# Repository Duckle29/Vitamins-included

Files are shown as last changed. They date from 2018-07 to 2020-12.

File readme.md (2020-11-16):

View this project on [CADLAB.io](https://cadlab.io/project/1862).   
View the [iBOM](https://duckle29.github.io/Vitamins-included/ibom.html)

# Vitamins Included

This repository contains all files necesarry to make the Let's split keyboard variant "Vitamins included"

Files are not guarranteed to be in sync outside of tagged releases. They aren't on releases either, but they should be ;)

The kit for these PCBs are sold at [Novelkeys](https://novelkeys.xyz), 
the firmware for the keyboard is [QMK](https://github.com/qmk/qmk_firmware/tree/master/keyboards/vitamins_included)

To edit these, you need kicad 5 or later. Missing footprints can be found [here](https://github.com/Duckle29/kicad-footprints), on seperate branches, but should be included in KiCAD libraries eventually. You can check for open pull-requests by me on the upstream repo to see the status on those.

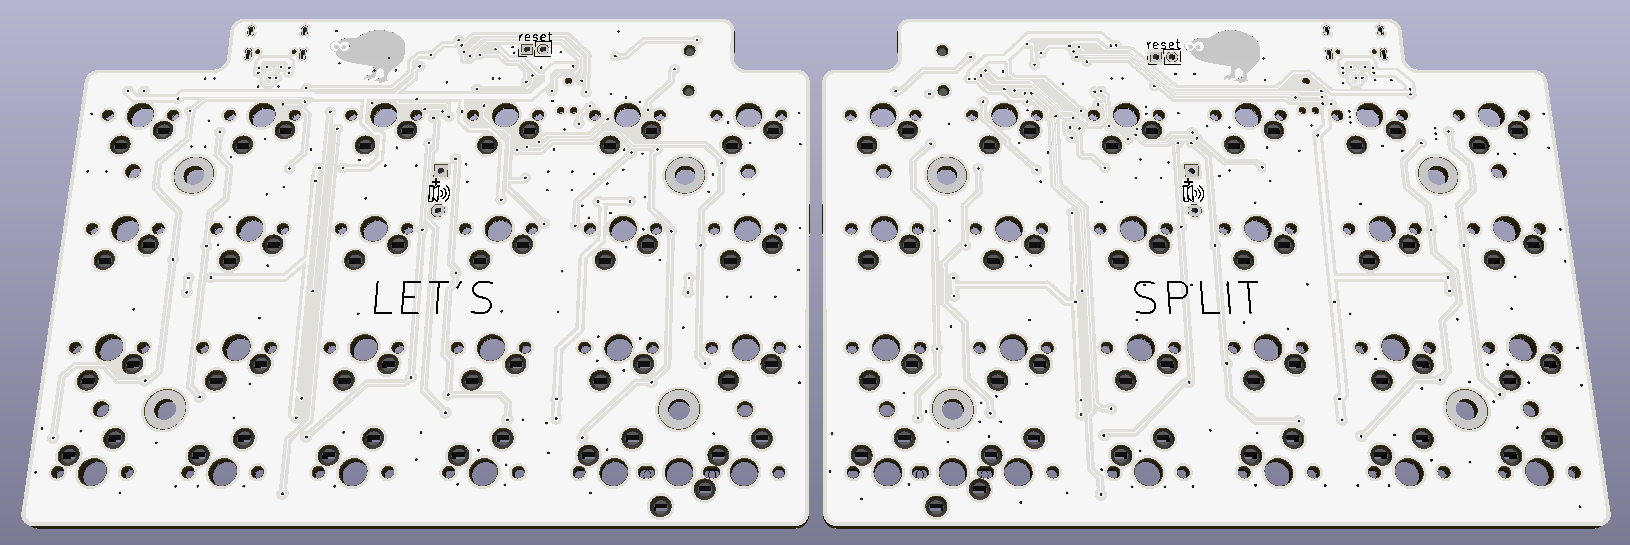
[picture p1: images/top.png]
top render

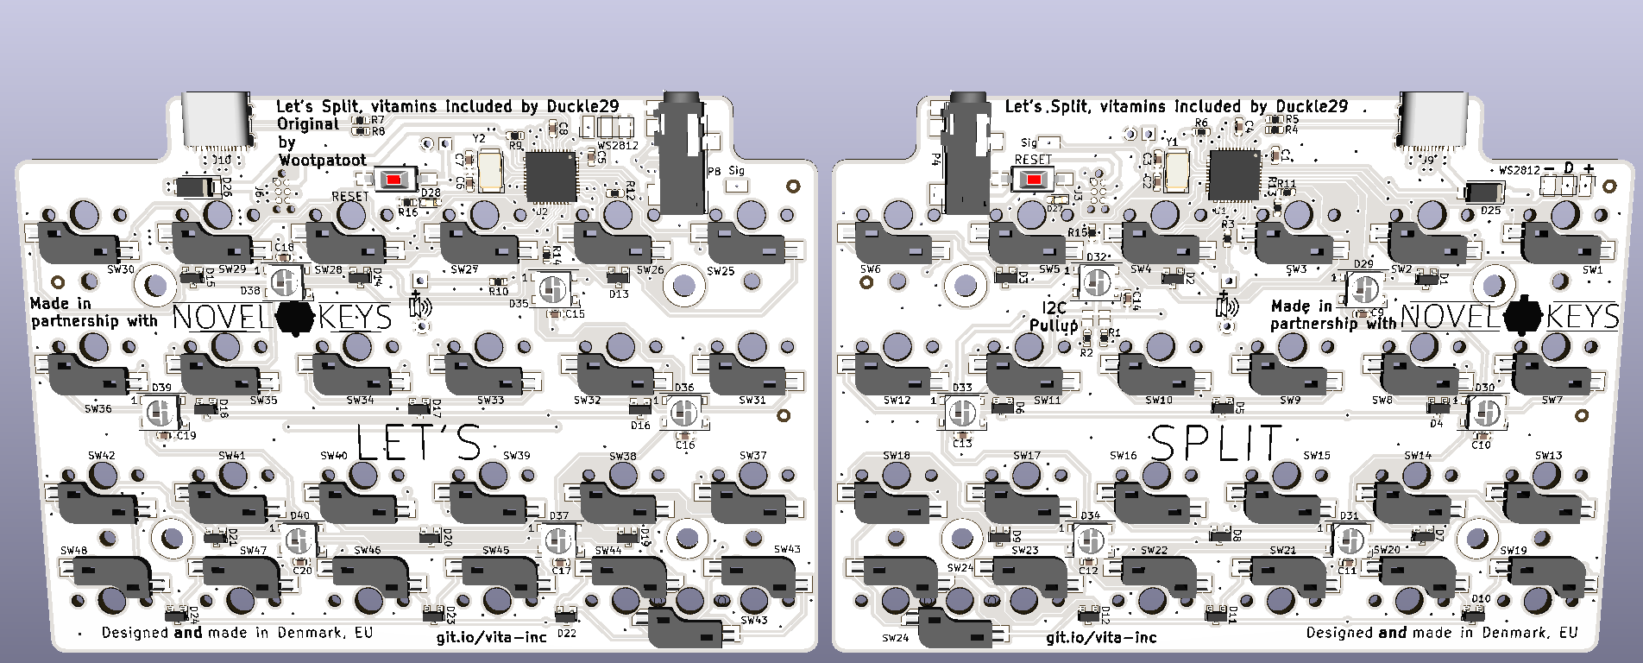
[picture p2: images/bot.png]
bottom render


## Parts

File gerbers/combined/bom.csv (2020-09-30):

Id | Designator | Package | Quantity | Designation | Supplier and ref
1 | R26,R25 | R_0603_1608Metric | 2 | 100k
2 | R24,R23,R22,R21,R13,R15,R3,R11,R16,R10,R12,R14 | R_0603_1608Metric | 12 | 220R
3 | SW6,SW29,SW14,SW22,SW17,SW9,SW1,SW20,SW15,SW23,SW7,SW8,SW11,SW12,SW21,SW4,SW24,SW18,SW5,SW2,SW19,SW16,SW3,SW13,SW10,SW24,SW43,SW30,SW48,SW35,SW32,SW39,SW28,SW40,SW27,SW38,SW46,SW33,SW26,SW34,SW36,SW43,SW44,SW42,SW37,SW41,SW47,SW31,SW25,SW45 | Kailh-socket | 50 | Socket
4 | D41,D44,D42,D43 | SOT-143 | 4 | PRTR5V0U2X
5 | D26,D25 | D_SMA | 2 | SS210ATR
6 | D6,D4,D8,D9,D10,D2,D1,D3,D7,D12,D11,D5,D22,D18,D23,D24,D21,D19,D15,D14,D13,D20,D17,D16 | SOT-23 | 24 | BAV70
7 | D30,D34,D33,D29,D31,D32,D35,D40,D36,D39,D37,D38 | LED_WS2812B_PLCC4_5.0x5.0mm_P3.2mm | 12 | WS2812B
8 | C3,C2,C7,C6 | C_0603_1608Metric | 4 | 18pF
9 | J3,J6 | Tag-Connect_TC2030-IDC-NL_2x03_P1.27mm_Vertical | 2 | ISP
10 | C9,C14,C13,C11,C4,C10,C1,C12,C19,C18,C16,C17,C15,C20,C5,C8 | C_0603_1608Metric | 16 | 1uF
11 | P3,P6 | SMD_PAD_1x03_Pitch2.54mm | 2 | WS2812
12 | JP5,JP6 | SolderJumper-3_P1.3mm_Bridged12_RoundedPad1.0x1.5mm | 2 | WS_OUT
13 | R1,R2,R6,R9 | R_0603_1608Metric | 4 | 4K7
14 | G***,G*** | kiwi12.5mm | 2 | LOGO
15 | J14,J7,J15,J12,J11,J13,J16,J17,J21,J24,J18,J8,J22,J19,J20,J23 | TestPoint_Pad_D1.5mm | 16 | Conn_01x01
16 | D27,D28 | LED_0603_1608Metric_Castellated | 2 | SML-D12U1WT86
17 | U1,U2 | QFN44G-0.5-7X7MM | 2 | ATMega32U4
18 | REF**,REF**,REF**,REF**,REF**,REF**,REF**,REF** | MountingHole_2.2mm_M2 | 8 | MountingHole_2.2mm_M2
19 | G***,G*** | NovelKeys | 2 | LOGO
20 | SW49,SW50 | SW_SPST_FSMSM | 2 | FSMSM
21 | REF**,REF**,REF**,REF**,REF**,REF**,REF**,REF** | 1pin | 8 | 1pin
22 | FID1,FID2,FID6,FID5,FID4,FID3 | Fiducial_1mm_Dia_2mm_Outer | 6 | Fiducial
23 | JP2,JP1 | Solder-jumper-NO | 2 | I2C pullup
24 | J2,J4 | PinHeader_1x02_P2.54mm_Vertical | 2 | reset
25 | Y1,Y2 | Crystal_SMD_Abracon_ABM3-2pin_5.0x3.2mm | 2 | 16MHz
26 | J9,J10 | USB_C_Receptacle_Palconn_UTC16-G | 2 | UTC16-G
27 | P4,P8 | SJ-4351X-SMT | 2 | SJ-43514-SMT
28 | R17,R18,R20,R19 | R_0603_1608Metric | 4 | 5K1
29 | J25,J26 | Buzzer_Mallory_AST1109MLTRQ | 2 | Buzzer_piezo
30 | J1 | Buzzer_12x9.5RM7.6 | 1 | Speaker
31 | JP4,JP3 | SolderJumper-3_P1.3mm_Bridged12_RoundedPad1.0x1.5mm | 2 | WS_MODE
32 | R4,R5,R7,R8 | R_0603_1608Metric | 4 | 22R
33 | J5 | Buzzer_12x9.5RM7.6 | 1 | Buzzer

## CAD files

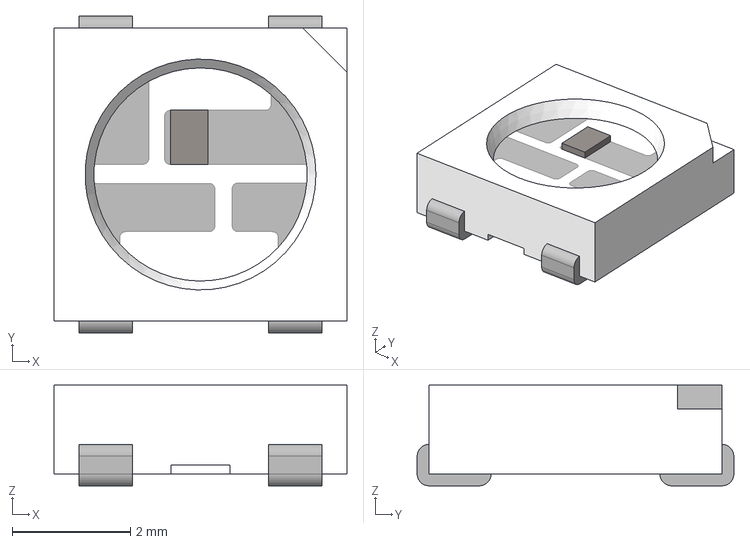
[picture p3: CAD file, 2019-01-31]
3D-models/WS2812_RGB_LED_updated.stp
4.95 x 5.35 x 1.70 mm

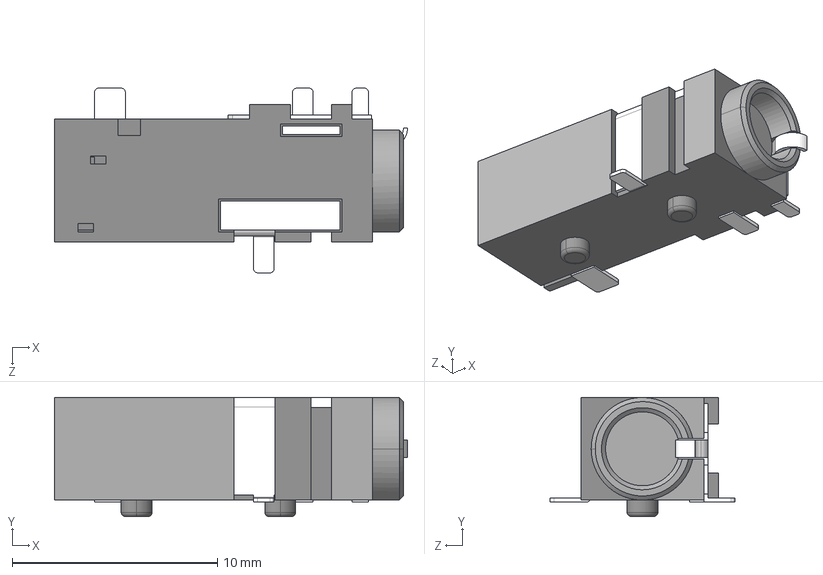
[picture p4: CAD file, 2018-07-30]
3D-models/CUI_SJ-43514-SMT-TR.step
17.2 x 5.80 x 9.00 mm

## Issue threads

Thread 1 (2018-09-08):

Kailh low profile sockets

AlexanderElias, 2018-09-08:
Hello awesome project products. I have been ordering parts from novel keys.

Does this board support Kailh low profile sockets?

Duckle29, 2018-09-08:
It uses the (currently sold out) MX sockets: https://novelkeys.xyz/products/kailh-pcb-sockets

AlexanderElias, 2018-09-09:
Bummer. Do you have or know of any other PCB designs that use the kailh low profile choc sockets?

Thanks!

Duckle29, 2018-09-10:
None that I'm aware of, sorry

Closed 2018-09-09.

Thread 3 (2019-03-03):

ISP and unknown components

happenslol, 2019-03-03:
Hey man, first of all, huge thanks for putting this out here! It's been a big help to me in working on my own keyboard PCB design. However, I had a few questions about the components you're using for this project and was hoping you could help me out.

First of all, if I understand correctly, the "ISP" pins (J3 and J6 in the schematic) are used to flash a chip without a bootloader. However, I can't see anywhere what type of ISP and what type of connector is actually used to connect to this. Is it just a generic ISP programmer and the pins are soldered to? Or is there an actual connector that can be used for this?

The second thing is the parts D27 and D28. Your BOM only annotates these with "red" - does this mean any red LED will do here? I assume that this is just to indicate power to the PCB, is that correct?

My last question is about the parts P3 and P6. These have the annotation "WS2812", but they do not appear on the BOM. They are hooked into the same circuit the LEDs and the name fits too, so I assume these are LEDs too, but they don't fit the footprint of a WS2812 and don't have enough pins. What are these meant to be used for?

Thanks in advance for any answers you can give me. I'd gladly make a PR with more annotations to these parts if you tell me about them, so that's it's easier to get a hold of all components needed to build this board for other people too.

Duckle29, 2019-03-03:
Hey there.

The ISP footprints are designed for use with a [TC2030-NL probe](http://www.tag-connect.com/node/23)

It allows for just an SMD footprint and as such ads no cost to the board. You can see it demonstrated [here](https://www.youtube.com/watch?v=dtch7CDxHiI).
The previous version used a normal 2x3 0.1" header, and a pogo-pin jig I printed.

As for D27 and D28, those are just red LEDs, I'll let my boardhouse pick the cheapest they can find. They're used by QMK-DFU to give primitive status indication :)

P3 and P6 are meant to be used for extending the onboard WS2812 string.
If you have the latest version, you can see that I added some jumpers that'll allow you to configure how the onboard LEDs are connected. The standard being MCU -> onboard -> P3/P6, however, they can be configured in other ways (described on a qmk.fm page that I'm waiting to make a PR for until these have gone through production :) )

If you're looking at making a batch of this particular repo, be aware that the files are untested, and some issues (rotated ws2812 footprints) have only recently been resolved, as we are moving to have 100 made. Additionally, the  USB-C connector is a bit hard to source but is used as it is a good quality connector that my boardhouse can source cheaply.

As for a timeframe, I'd say a few months.

happenslol, 2019-03-03:
Thanks for the super quick response!
That clears it up. I'll probably just get a simple AVR programmer then and use one of those connectors. Nice work on the programmer in that video though, I especially love that switch used to start the flashing =) Should put a keycap on it though...

And thanks for the heads up, I've made my own pcb and taken a lot from this schematic and the original let's split, but I won't be using these files directly. I've also replaced the USB connector already, it was pretty much impossible to find yours through google.

Do you want me to add more descriptions/comments to the mentioned parts and make a PR?

Duckle29, 2019-03-03:
Ah cool. Yeah the connector is solidly a "made in china" part, and sold in quantities that doesn't make sense for most people :)

I don't really see how you'd add those descriptions comments, and I probably wouldn't merge the PR, so I don't want you to waste your time on it :)

Something like the BOM for the LEDs might be updated, so far the fab told me it was good enough for a quote, but they need more specific part numbers for some of the parts, so the BOM should be updated before production starts.

As for the programming header, the footprint is named TC2030 iirc, but as it's not an actual component, it's not present in the position files or the BOM.

The usage of P3 and P6 will be described on qmk.fm once I make a PR for [these](https://github.com/Duckle29/qmk.fm/blob/gh-pages/_pages/keyboards/vitamins_included.md) changes :)

happenslol, 2019-03-03:
My idea would've been to just add another field to the symbol properties in the schematic, and maybe add the links you provided as the datasheet, just to point people in the right direction. Otherwise, I would've just added the information to the README, but it's if you're just using this repo for yourself anyways.

Thanks again for all the information, and the PR link. I'll be watching the stock for the board and probably pick one up when you do that production run =)

Duckle29, 2019-03-03:
I updated the BOM for the LEDs, I found some nicely priced ones, and figured I might as well :)

As for the TC2030, adding that link as the datasheet would be fine :) As for the use of the P3 and P6, I think the qmk.fm page describes that fairly well, and I don't think that fits this repo.

This repo is meant to hold all the files necessary to produce these boards, and I'd keep the documentation of its use elsewhere (qmk.fm if allowed :) )

Closed 2019-03-04.

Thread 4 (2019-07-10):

Decide if I want to replace 4k7 resistors with 5k1 to reduce BOM items

Duckle29, 2019-07-10:

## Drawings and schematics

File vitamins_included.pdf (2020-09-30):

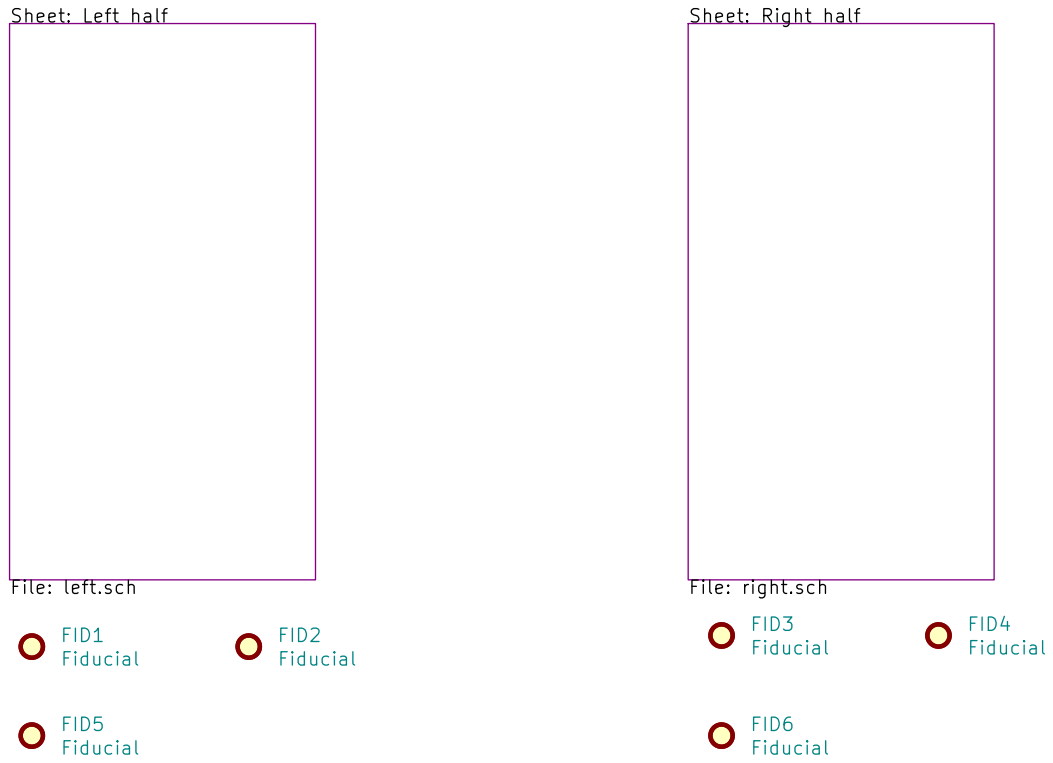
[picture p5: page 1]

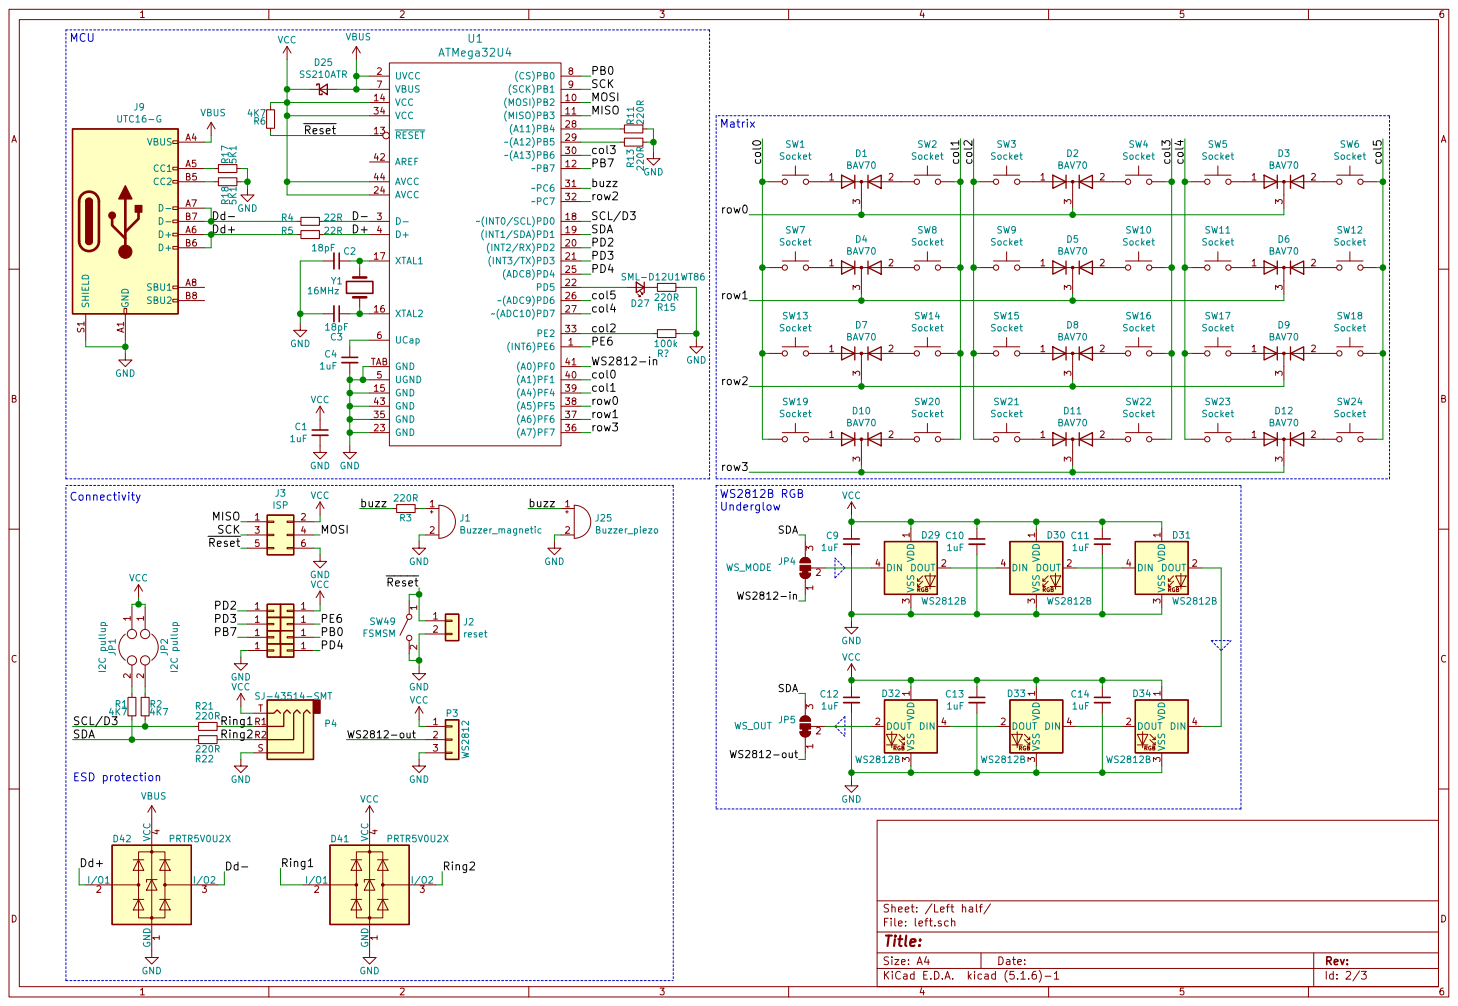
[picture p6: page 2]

3 D6 BAV70 SW3 Socket SW4 Socket SW5 Socket SW6 Socket 1 2

3 D9 BAV70 SW14 Socket SW15 Socket SW16 Socket SW17 Socket GND

Id: 2/3 Title: File: left.sch Sheet: /Left half/

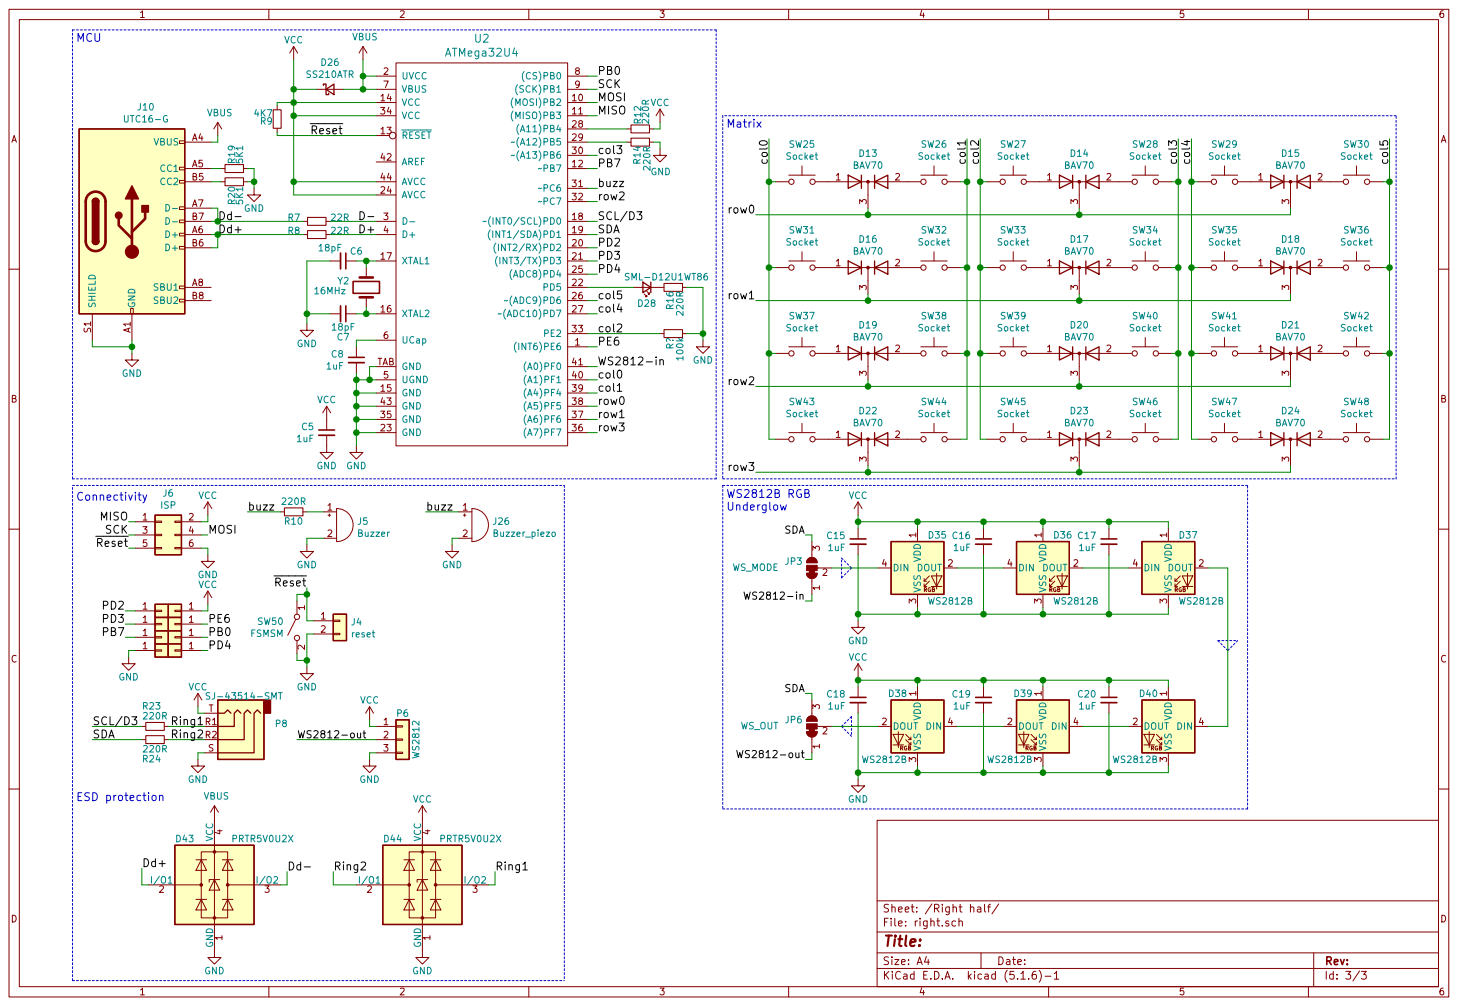
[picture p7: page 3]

3 D24 BAV70 SW44 Socket SW45 Socket SW46 Socket SW47 Socket SW48 Socket D26 SS210ATR

3 D20 BAV70 SW38 Socket SW39 Socket SW40 Socket SW41 Socket SW42 Socket SW43 Socket Reset Ring1

VCC GND GND GND

3 D19 BAV70 SW36 Socket SW35 Socket SW34 Socket SW33 Socket (INT6)PE6 1

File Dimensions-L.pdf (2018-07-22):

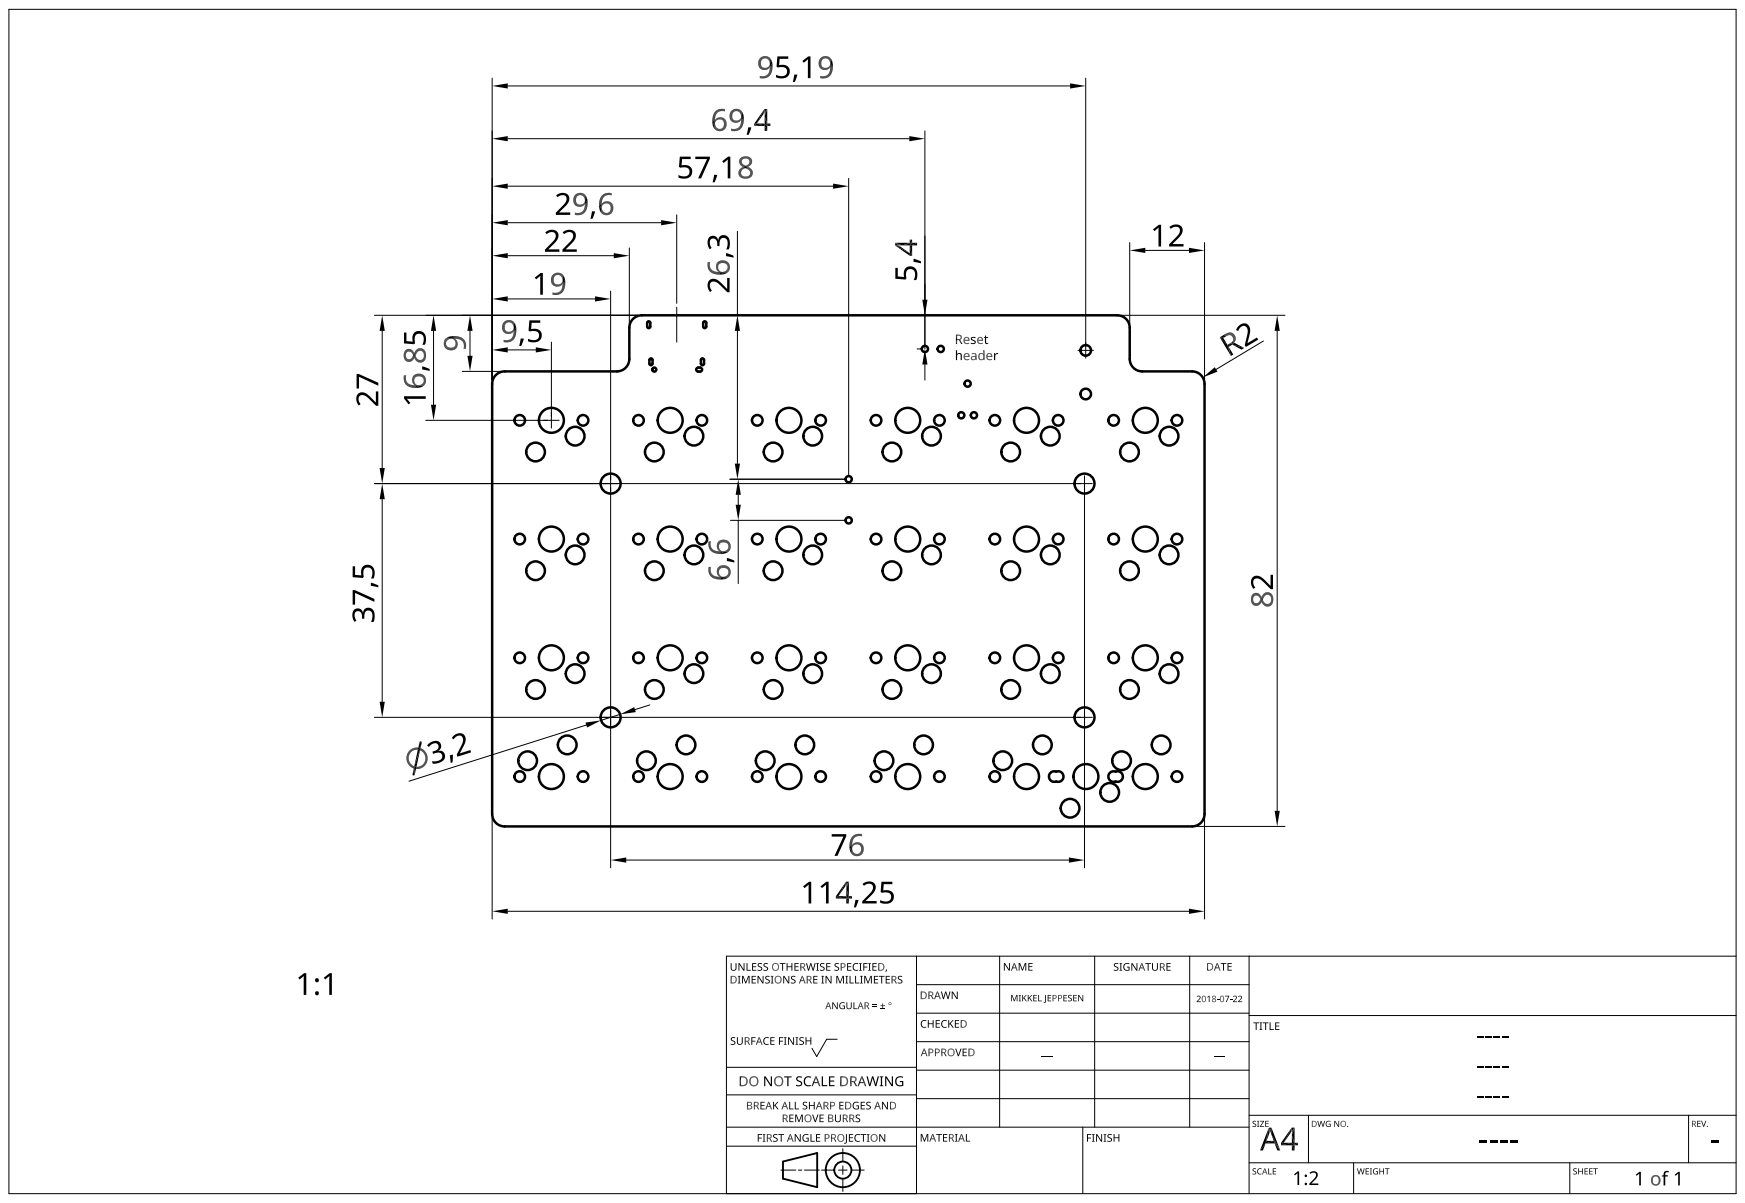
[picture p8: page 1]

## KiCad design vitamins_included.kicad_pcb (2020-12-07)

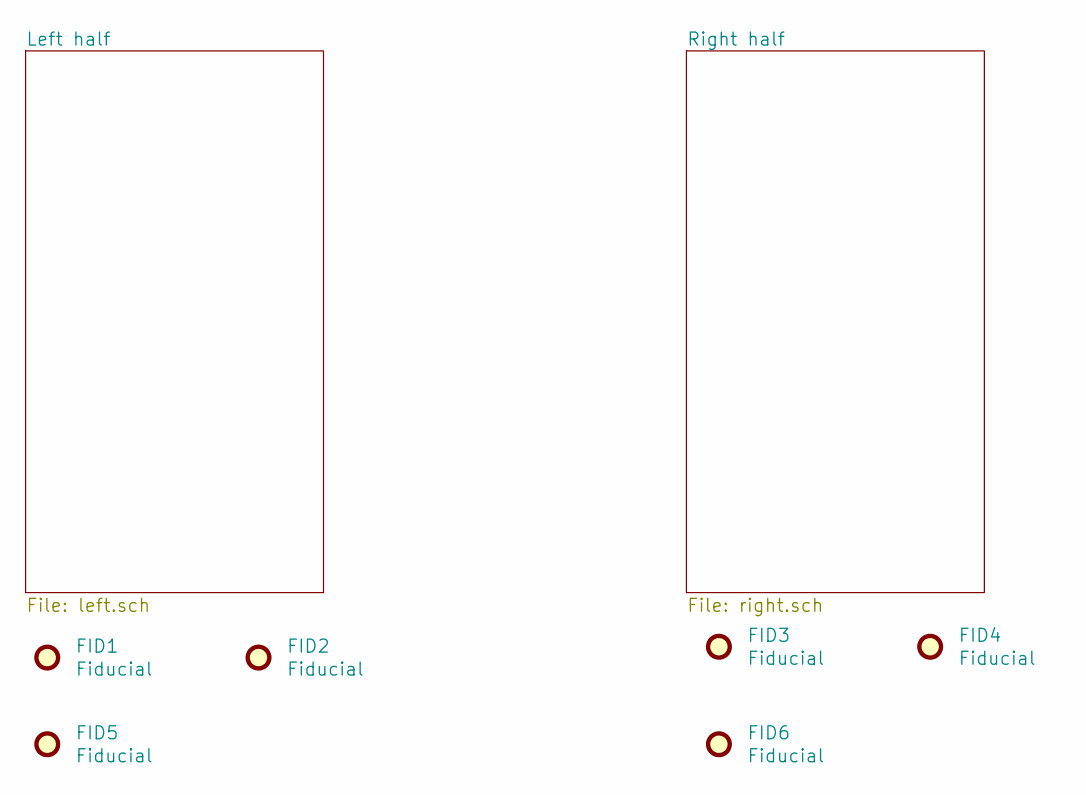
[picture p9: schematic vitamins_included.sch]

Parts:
FID1, FID2, FID3, FID4, FID5, FID6: Fiducial; Fiducial_1mm_Dia_2mm_Outer

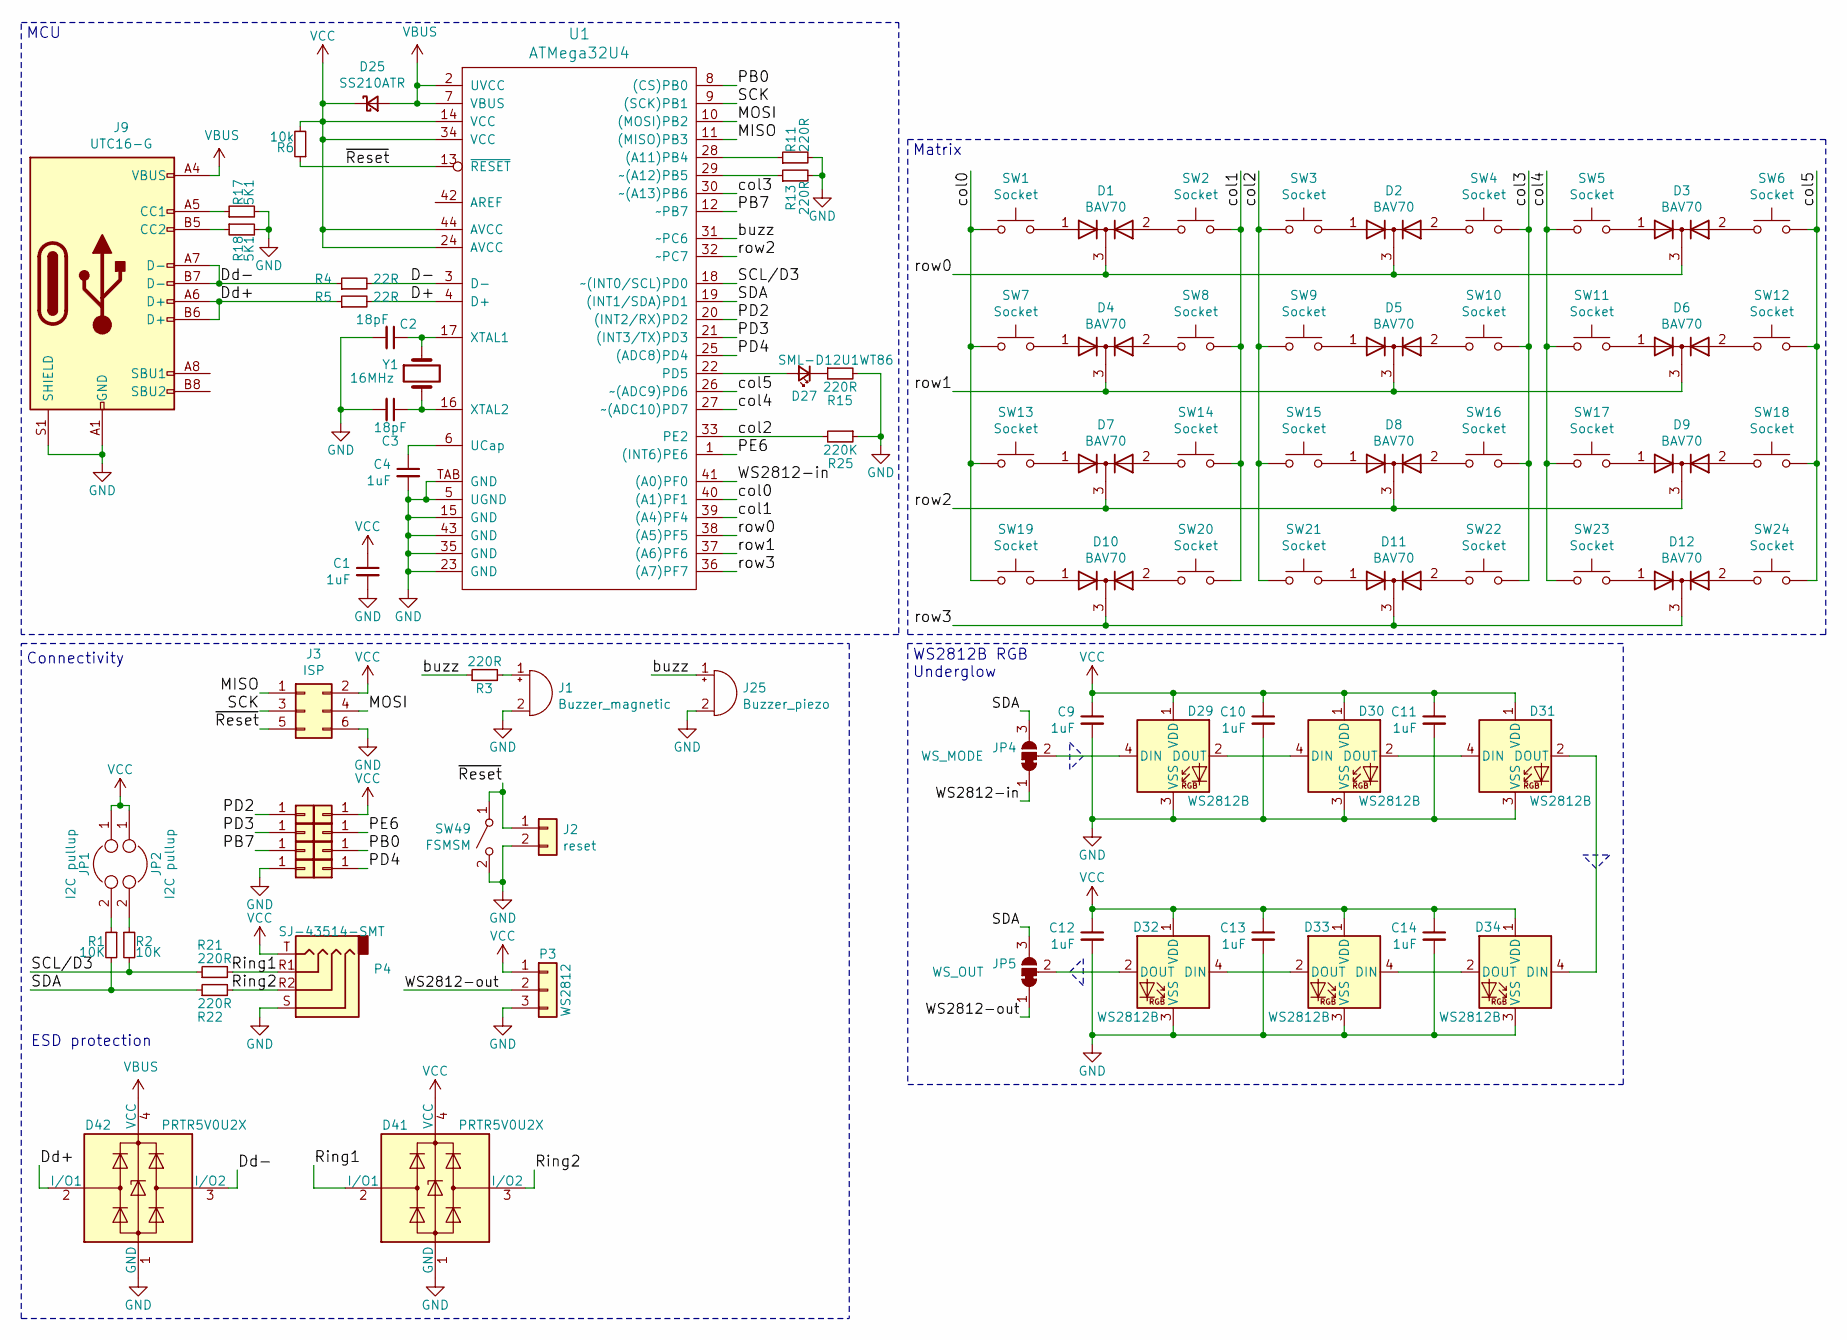
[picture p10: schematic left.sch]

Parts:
C1, C4, C9, C10, C11, C12, C13, C14: 1uF; C_0603_1608Metric
C2, C3: 18pF; C_0603_1608Metric
D1, D2, D3, D4, D5, D6, D7, D8, D9, D10, D11, D12: BAV70; SOT-23
D25: SS210ATR; D_SMA
D27: SML-D12U1WT86; LED_0603_1608Metric_Castellated
D29, D30, D31, D32, D33, D34: WS2812B; LED_WS2812B_PLCC4_5.0x5.0mm_P3.2mm
D41, D42: PRTR5V0U2X; SOT-143
J1: Buzzer_magnetic; Buzzer_12x9.5RM7.6
J2: reset; PinHeader_1x02_P2.54mm_Vertical
J3: ISP; Tag-Connect_TC2030-IDC-NL_2x03_P1.27mm_Vertical
J7, J11, J12, J13, J14, J15, J16, J17: Conn_01x01; TestPoint_Pad_D1.5mm
J9: UTC16-G; USB_C_Receptacle_Palconn_UTC16-G
J25: Buzzer_piezo; Buzzer_Mallory_AST1109MLTRQ
JP1, JP2: I2C pullup; Solder-jumper-NO
JP4: WS_MODE; SolderJumper-3_P1.3mm_Bridged12_RoundedPad1.0x1.5mm
JP5: WS_OUT; SolderJumper-3_P1.3mm_Bridged12_RoundedPad1.0x1.5mm
P3: WS2812; SMD_PAD_1x03_Pitch2.54mm
P4: SJ-43514-SMT; SJ-4351X-SMT
R1, R2: 10K; R_0603_1608Metric
R3, R11, R13, R15, R21, R22: 220R; R_0603_1608Metric
R4, R5: 22R; R_0603_1608Metric
R6: 10k; R_0603_1608Metric
R17, R18: 5K1; R_0603_1608Metric
R25: 220K; R_0603_1608Metric
SW1, SW2, SW3, SW4, SW5, SW6, SW7, SW8, SW9, SW10, SW11, SW12, SW13, SW14, SW15, SW16, SW17, SW18, SW19, SW20, SW21, SW22, SW23, SW24: Socket; Kailh-socket
SW49: FSMSM; SW_SPST_FSMSM
U1: ATMega32U4; QFN44G-0.5-7X7MM
Y1: 16MHz; Crystal_SMD_Abracon_ABM3-2pin_5.0x3.2mm

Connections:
/Left half/D+: R5.2, U1.4 (D+)
/Left half/D-: R4.2, U1.3 (D-)
/Left half/Dd+: D42.2 (I/O1), J9.A6 (D+), J9.B6 (D+), R5.1
/Left half/Dd-: D42.3 (I/O2), J9.A7 (D-), J9.B7 (D-), R4.1
/Left half/MISO: J3.1, U1.11 ((MISO)PB3); also elsewhere on the board
/Left half/MOSI: J3.4, U1.10 ((MOSI)PB2); also elsewhere on the board
/Left half/PB0: J15.1, U1.8 ((CS)PB0)
/Left half/PB7: J14.1, U1.12 (~~PB7)
/Left half/PD2: J12.1, U1.20 ((INT2/RX)PD2)
/Left half/PD3: J7.1, U1.21 ((INT3/TX)PD3)
/Left half/PD4: J11.1, U1.25 ((ADC8)PD4)
/Left half/PE6: J13.1, U1.1 ((INT6)PE6)
/Left half/Ring1: D41.2 (I/O1), P4.R1, R21.2
/Left half/Ring2: D41.3 (I/O2), P4.R2, R22.2
/Left half/SCK: J3.3, U1.9 ((SCK)PB1); also elsewhere on the board
/Left half/SCL/D3: R2.2, R21.1, U1.18 (~~(INT0/SCL)PD0)
/Left half/SDA: JP4.3 (B), JP5.3 (B), R1.2, R22.1, U1.19 ((INT1/SDA)PD1)
/Left half/WS2812-in: JP4.1 (A), U1.41 ((A0)PF0)
/Left half/WS2812-out: JP5.1 (A), P3.2
/Left half/buzz: J25.1 (-), R3.1, U1.31 (~~PC6)
/Left half/col0: SW1.1, SW7.1, SW13.1, SW19.1, U1.40 ((A1)PF1)
/Left half/col1: SW2.2, SW8.2, SW14.2, SW20.2, U1.39 ((A4)PF4)
/Left half/col2: R25.2, SW3.1, SW9.1, SW15.1, SW21.1, U1.33 (PE2)
/Left half/col3: SW4.2, SW10.2, SW16.2, SW22.2, U1.30 (~~(A13)PB6)
/Left half/col4: SW5.1, SW11.1, SW17.1, SW23.1, U1.27 (~~(ADC10)PD7)
/Left half/col5: SW6.2, SW12.2, SW18.2, SW24.2, U1.26 (~~(ADC9)PD6); also elsewhere on the board
/Left half/row0: D1.3 (K), D2.3 (K), D3.3 (K), U1.38 ((A5)PF5)
/Left half/row1: D4.3 (K), D5.3 (K), D6.3 (K), U1.37 ((A6)PF6)
/Left half/row2: D7.3 (K), D8.3 (K), D9.3 (K), U1.32 (~~PC7)
/Left half/row3: D10.3 (K), D11.3 (K), D12.3 (K), U1.36 ((A7)PF7)
/Left half/~Reset: J2.1, J3.5, R6.1, SW49.1 (A), U1.13 (~RESET~)
unnamed: C2.1, U1.17 (XTAL1), Y1.1
unnamed: C3.1, U1.16 (XTAL2), Y1.2
unnamed: C4.1, U1.6 (UCap)
unnamed: D1.1 (A), SW1.2
unnamed: D1.2 (A), SW2.1
unnamed: D2.1 (A), SW3.2
unnamed: D2.2 (A), SW4.1
unnamed: D3.1 (A), SW5.2
unnamed: D3.2 (A), SW6.1
unnamed: D4.1 (A), SW7.2
unnamed: D4.2 (A), SW8.1
unnamed: D5.1 (A), SW9.2
unnamed: D5.2 (A), SW10.1
unnamed: D6.1 (A), SW11.2
unnamed: D6.2 (A), SW12.1
unnamed: D7.1 (A), SW13.2
unnamed: D7.2 (A), SW14.1
unnamed: D8.1 (A), SW15.2
unnamed: D8.2 (A), SW16.1
unnamed: D9.1 (A), SW17.2
unnamed: D9.2 (A), SW18.1
unnamed: D10.1 (A), SW19.2
unnamed: D10.2 (A), SW20.1
unnamed: D11.1 (A), SW21.2
unnamed: D11.2 (A), SW22.1
unnamed: D12.1 (A), SW23.2
unnamed 90: D12.2 (A), SW24.1; also elsewhere on the board
unnamed: D27.1 (K), R15.1
unnamed: D27.2 (A), U1.22 (PD5)
unnamed: D29.2 (DOUT), D30.4 (DIN)
unnamed: D29.4 (DIN), JP4.2 (C)
unnamed: D30.2 (DOUT), D31.4 (DIN)
unnamed: D31.2 (DOUT), D34.4 (DIN)
unnamed: D32.2 (DOUT), JP5.2 (C)
unnamed: D32.4 (DIN), D33.2 (DOUT)
unnamed: D33.4 (DIN), D34.2 (DOUT)
unnamed: J1.1 (-), R3.2
unnamed: J9.A5 (CC1), R17.1
unnamed: J9.B5 (CC2), R18.1
unnamed: JP1.2, R1.1
unnamed: JP2.2, R2.1
unnamed: R11.1, U1.28 ((A11)PB4)
unnamed: R13.1, U1.29 (~~(A12)PB5)
VBUS: D25.2 (A), D42.4 (VCC), J9.A4 (VBUS), J9.A9 (VBUS), J9.B4 (VBUS), J9.B9 (VBUS), U1.2 (UVCC), U1.7 (VBUS); also elsewhere on the board
VCC: C1.1, C9.1, C10.1, C11.1, C12.1, C13.1, C14.1, D25.1 (K), D29.1 (VDD), D30.1 (VDD), D31.1 (VDD), D32.1 (VDD), D33.1 (VDD), D34.1 (VDD), D41.4 (VCC), J3.2, J17.1, JP1.1, JP2.1, P3.1, P4.T, R6.2, U1.14 (VCC), U1.24 (AVCC), U1.34 (VCC), U1.44 (AVCC); also elsewhere on the board

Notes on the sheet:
MCU
WS2812B RGB Underglow
Matrix
Connectivity
ESD protection

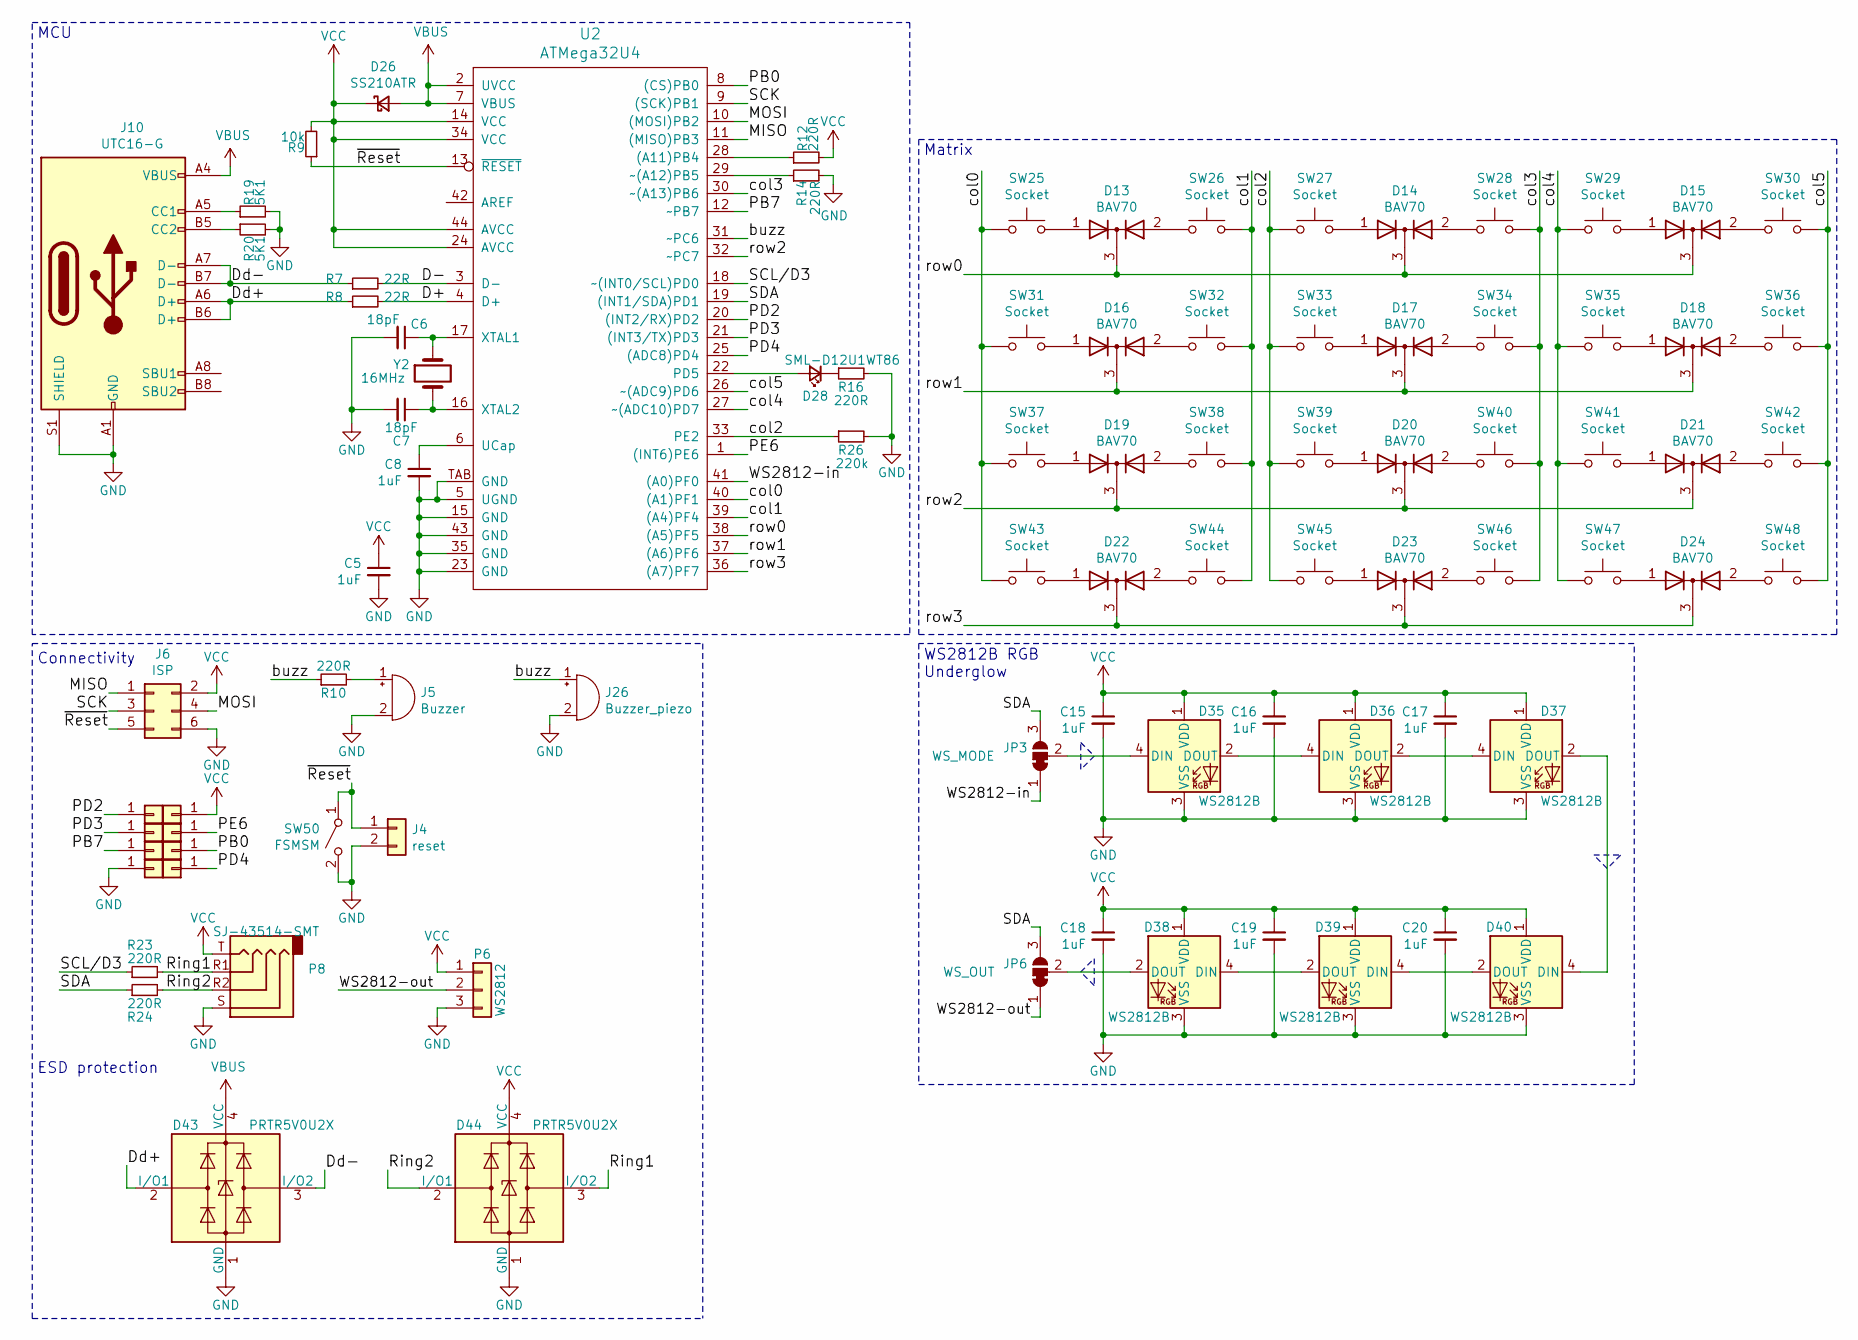
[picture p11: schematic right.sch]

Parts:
C5, C8, C15, C16, C17, C18, C19, C20: 1uF; C_0603_1608Metric
C6, C7: 18pF; C_0603_1608Metric
D13, D14, D15, D16, D17, D18, D19, D20, D21, D22, D23, D24: BAV70; SOT-23
D26: SS210ATR; D_SMA
D28: SML-D12U1WT86; LED_0603_1608Metric_Castellated
D35, D36, D37, D38, D39, D40: WS2812B; LED_WS2812B_PLCC4_5.0x5.0mm_P3.2mm
D43, D44: PRTR5V0U2X; SOT-143
J4: reset; PinHeader_1x02_P2.54mm_Vertical
J5: Buzzer; Buzzer_12x9.5RM7.6
J6: ISP; Tag-Connect_TC2030-IDC-NL_2x03_P1.27mm_Vertical
J8, J18, J19, J20, J21, J22, J23, J24: Conn_01x01; TestPoint_Pad_D1.5mm
J10: UTC16-G; USB_C_Receptacle_Palconn_UTC16-G
J26: Buzzer_piezo; Buzzer_Mallory_AST1109MLTRQ
JP3: WS_MODE; SolderJumper-3_P1.3mm_Bridged12_RoundedPad1.0x1.5mm
JP6: WS_OUT; SolderJumper-3_P1.3mm_Bridged12_RoundedPad1.0x1.5mm
P6: WS2812; SMD_PAD_1x03_Pitch2.54mm
P8: SJ-43514-SMT; SJ-4351X-SMT
R7, R8: 22R; R_0603_1608Metric
R9: 10k; R_0603_1608Metric
R10, R12, R14, R16, R23, R24: 220R; R_0603_1608Metric
R19, R20: 5K1; R_0603_1608Metric
R26: 220k; R_0603_1608Metric
SW25, SW26, SW27, SW28, SW29, SW30, SW31, SW32, SW33, SW34, SW35, SW36, SW37, SW38, SW39, SW40, SW41, SW42, SW43, SW44, SW45, SW46, SW47, SW48: Socket; Kailh-socket
SW50: FSMSM; SW_SPST_FSMSM
U2: ATMega32U4; QFN44G-0.5-7X7MM
Y2: 16MHz; Crystal_SMD_Abracon_ABM3-2pin_5.0x3.2mm

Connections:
/Right half/D+: R8.2, U2.4 (D+)
/Right half/D-: R7.2, U2.3 (D-)
/Right half/Dd+: D43.2 (I/O1), J10.A6 (D+), J10.B6 (D+), R8.1
/Right half/Dd-: D43.3 (I/O2), J10.A7 (D-), J10.B7 (D-), R7.1
/Right half/MISO: J6.1, U2.11 ((MISO)PB3); also elsewhere on the board
/Right half/MOSI: J6.4, U2.10 ((MOSI)PB2); also elsewhere on the board
/Right half/PB0: J22.1, U2.8 ((CS)PB0)
/Right half/PB7: J21.1, U2.12 (~~PB7)
/Right half/PD2: J8.1, U2.20 ((INT2/RX)PD2)
/Right half/PD3: J19.1, U2.21 ((INT3/TX)PD3)
/Right half/PD4: J24.1, U2.25 ((ADC8)PD4)
/Right half/PE6: J20.1, U2.1 ((INT6)PE6)
/Right half/Ring1: D44.3 (I/O2), P8.R1, R23.2
/Right half/Ring2: D44.2 (I/O1), P8.R2, R24.2
/Right half/SCL/D3: R23.1, U2.18 (~~(INT0/SCL)PD0)
/Right half/SDA: JP3.3 (B), JP6.3 (B), R24.1, U2.19 ((INT1/SDA)PD1)
/Right half/WS2812-in: JP3.1 (A), U2.41 ((A0)PF0)
/Right half/WS2812-out: JP6.1 (A), P6.2
/Right half/buzz: J26.1 (-), R10.1, U2.31 (~~PC6)
/Right half/col0: SW25.1, SW31.1, SW37.1, SW43.1, U2.40 ((A1)PF1); also elsewhere on the board
/Right half/col1: SW26.2, SW32.2, SW38.2, SW44.2, U2.39 ((A4)PF4)
/Right half/col2: R26.1, SW27.1, SW33.1, SW39.1, SW45.1, U2.33 (PE2)
/Right half/col3: SW28.2, SW34.2, SW40.2, SW46.2, U2.30 (~~(A13)PB6)
/Right half/col4: SW29.1, SW35.1, SW41.1, SW47.1, U2.27 (~~(ADC10)PD7)
/Right half/col5: SW30.2, SW36.2, SW42.2, SW48.2, U2.26 (~~(ADC9)PD6)
/Right half/row0: D13.3 (K), D14.3 (K), D15.3 (K), U2.38 ((A5)PF5)
/Right half/row1: D16.3 (K), D17.3 (K), D18.3 (K), U2.37 ((A6)PF6)
/Right half/row2: D19.3 (K), D20.3 (K), D21.3 (K), U2.32 (~~PC7)
/Right half/row3: D22.3 (K), D23.3 (K), D24.3 (K), U2.36 ((A7)PF7)
/Right half/~Reset: J4.1, J6.5, R9.1, SW50.1 (A), U2.13 (~RESET~)
unnamed: C6.1, U2.17 (XTAL1), Y2.1
unnamed: C7.1, U2.16 (XTAL2), Y2.2
unnamed: C8.1, U2.6 (UCap)
unnamed: D13.1 (A), SW25.2
unnamed: D13.2 (A), SW26.1
unnamed: D14.1 (A), SW27.2
unnamed: D14.2 (A), SW28.1
unnamed: D15.1 (A), SW29.2
unnamed: D15.2 (A), SW30.1
unnamed: D16.1 (A), SW31.2
unnamed: D16.2 (A), SW32.1
unnamed: D17.1 (A), SW33.2
unnamed: D17.2 (A), SW34.1
unnamed: D18.1 (A), SW35.2
unnamed: D18.2 (A), SW36.1
unnamed: D19.1 (A), SW37.2
unnamed: D19.2 (A), SW38.1
unnamed: D20.1 (A), SW39.2
unnamed: D20.2 (A), SW40.1
unnamed: D21.1 (A), SW41.2
unnamed: D21.2 (A), SW42.1
unnamed 109: D22.1 (A), SW43.2; also elsewhere on the board
unnamed: D22.2 (A), SW44.1
unnamed: D23.1 (A), SW45.2
unnamed: D23.2 (A), SW46.1
unnamed: D24.1 (A), SW47.2
unnamed: D24.2 (A), SW48.1
unnamed: D28.1 (K), R16.1
unnamed: D28.2 (A), U2.22 (PD5)
unnamed: D35.2 (DOUT), D36.4 (DIN)
unnamed: D35.4 (DIN), JP3.2 (C)
unnamed: D36.2 (DOUT), D37.4 (DIN)
unnamed: D37.2 (DOUT), D40.4 (DIN)
unnamed: D38.2 (DOUT), JP6.2 (C)
unnamed: D38.4 (DIN), D39.2 (DOUT)
unnamed: D39.4 (DIN), D40.2 (DOUT)
unnamed: J5.1 (-), R10.2
unnamed: J10.A5 (CC1), R19.1
unnamed: J10.B5 (CC2), R20.1
unnamed: R12.1, U2.28 ((A11)PB4)
unnamed: R14.1, U2.29 (~~(A12)PB5)
VBUS: D26.2 (A), D43.4 (VCC), J10.A4 (VBUS), J10.A9 (VBUS), J10.B4 (VBUS), J10.B9 (VBUS), U2.2 (UVCC), U2.7 (VBUS); also elsewhere on the board
VCC: C5.1, C15.1, C16.1, C17.1, C18.1, C19.1, C20.1, D26.1 (K), D35.1 (VDD), D36.1 (VDD), D37.1 (VDD), D38.1 (VDD), D39.1 (VDD), D40.1 (VDD), D44.4 (VCC), J6.2, J18.1, P6.1, P8.T, R9.2, R12.2, U2.14 (VCC), U2.24 (AVCC), U2.34 (VCC), U2.44 (AVCC); also elsewhere on the board

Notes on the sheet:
MCU
WS2812B RGB Underglow
Matrix
Connectivity
ESD protection

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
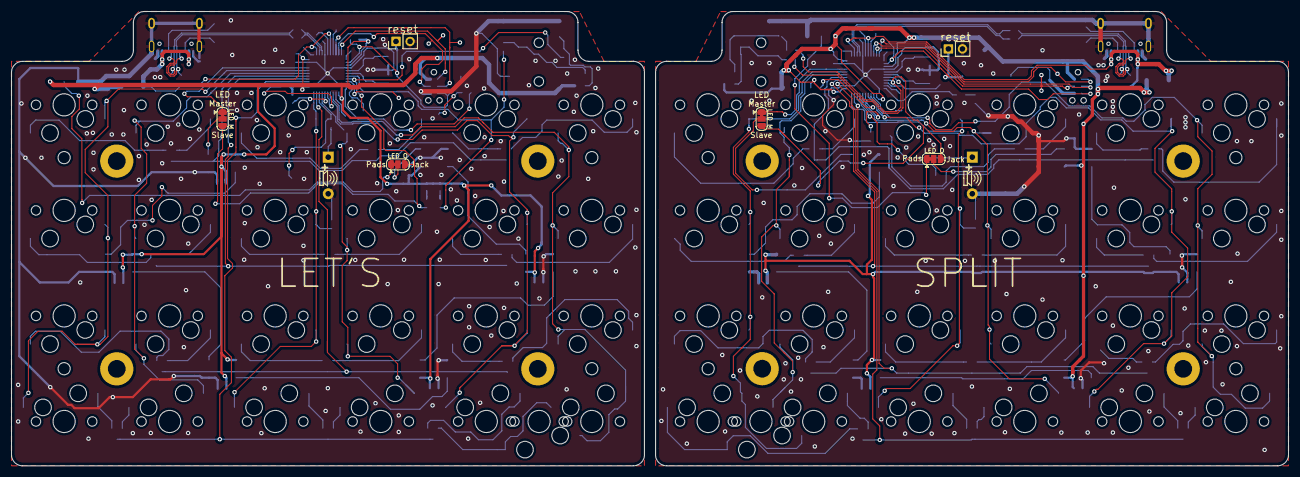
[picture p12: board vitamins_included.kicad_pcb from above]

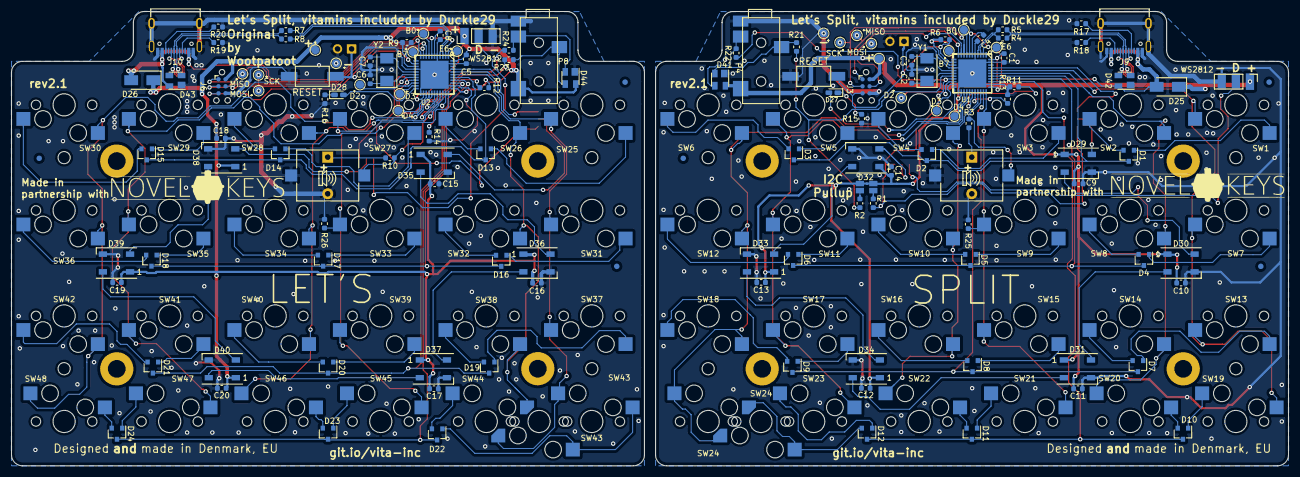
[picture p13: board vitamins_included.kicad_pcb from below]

Board: 2 copper layers, 230.5 x 82.0 mm, 194 parts (188 on the bottom side), 149 nets.

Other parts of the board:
J16#2, J16#3, J16#4, J16#5, J16#6, J16#7: Conn_01x01; TestPoint_Pad_D1.5mm
SW24#2, SW43#2: Socket; Kailh-socket

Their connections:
/Left half/MISO: J16#6.1; also elsewhere on the board
/Left half/MOSI: J16#5.1; also elsewhere on the board
/Left half/SCK: J16#4.1; also elsewhere on the board
/Left half/col5: SW24#2.2; also elsewhere on the board
/Right half/MISO: J16#2.1; also elsewhere on the board
/Right half/MOSI: J16#3.1; also elsewhere on the board
/Right half/col0: SW43#2.1; also elsewhere on the board
unnamed 90: SW24#2.1; also elsewhere on the board
unnamed 109: SW43#2.2; also elsewhere on the board

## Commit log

2018-07-19 Initial commit, moving project to it's own repo
    [BOM.csv, left.sch, lets_split_panel.kicad_pcb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]
2018-07-19 renamed files, and generated xy files
    [left.sch, lets_split_panel.kicad_pcb, lets_split_panel.sch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]
2018-07-19 Added BOM and 3D file
    [BOM.csv, Vitamins-included-BOM.csv, left.sch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]
2018-07-19 Added resistors to allow MCU to determin which half it is on
    [Vitamins-included-BOM.csv, left.sch, right.sch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]
2018-07-20 Changed to USB-C connector
    [BOM.csv, BOM_vitamins_included.csv, Vitamins-included-BOM.csv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]
2018-07-22 Added resistors to allow the firmware to determine version
    [BOM_vitamins_included.csv, left.sch, right.sch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]
2018-07-22 changed to rounded passive footprints
    [BOM_vitamins_included.csv, left.sch, right.sch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]
2018-07-22 Exported new 3d files
    [vitamins_included-left.stp, vitamins_included-right.stp, vitamins_included.kicad_pcb]
2018-07-22 Added Schematic pdf
2018-07-22 Added a Dimensions PDF for case-makers
2018-07-27 Switched to connectors
    [left.sch, right.sch, vitamins_included.kicad_pcb]
2018-07-27 Fixed 3Dmodels for sockets.Exported new renders
    [vitamins_included.kicad_pcb]
2018-07-27 Exported new fabriation files
    [BOM_vitamins_included.csv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]
2018-07-27 Ran DRC, fixed things
    [vitamins_included.kicad_pcb]
2018-07-27 Organized silkscreen
    [vitamins_included.kicad_pcb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]
2018-07-30 Added reset button, led, 3D models
    [BOM_vitamins_included.csv, CUI_SJ-43514-SMT-TR.step, UTC016.step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]
2018-08-03 Fixed schematic PDF
2018-09-03 Broke something. who knows
    [left.sch, right.sch, vitamins_included.kicad_pcb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]
2018-09-21 Production state
    [vitamins_included-all-pos.csv, vitamins_included-left-pos.csv, vitamins_included-right-pos.csv]
2018-11-27 Added WS2812B leds to one half
    [WS2812_RGB_LED_updated.stp, left.sch, right.sch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]
2018-11-27 started work on second half
    [right.sch, vitamins_included.kicad_pcb]
2019-01-31 Added ws2812 LEDs
    [vitamins_included-B.Cu.gbl, vitamins_included-B.Mask.gbs, vitamins_included-B.Paste.gbp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]
2019-01-31 Updated BOM
    [BOM_vitamins_included.csv]
2019-01-31 Added zipped gerbers
2019-02-21 Exported fabrication outputs for qoute
    [vitamins_included-B.Cu.gbl, vitamins_included-B.Mask.gbs, vitamins_included-B.Paste.gbp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]
2019-02-27 Fixed rotated LEDs, added config jumpers
    [left.sch, right.sch, vitamins_included-left.stp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]
2019-02-27 Exported new fabrication outputs
    [vitamins_included-B.Cu.gbl, vitamins_included-B.Mask.gbs, vitamins_included-B.Paste.gbp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]
2019-03-03 Added MPN to DFU LED
    [BOM_vitamins_included.csv, left.sch, right.sch]
2019-03-17 Fixed USB-C footprint
    [vitamins_included-B.Cu.gbl, vitamins_included-B.Mask.gbs, vitamins_included-B.Paste.gbp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]
2019-03-18 Updated gerbers
2019-03-27 Added X2 gerbers and updated BOM
    [BOM_vitamins_included.csv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]
2019-07-04 Added 5k1 CC resistors
    [left.sch, right.sch, vitamins_included.kicad_pcb]
2019-07-04 Genereated new gerbers
    [vitamins_included-B.Cu.gbr, vitamins_included-B.Mask.gbr, vitamins_included-B.Paste.gbr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]
2019-07-04 Added R17-20 to BOM
    [BOM_vitamins_included.csv]
2019-07-06 Switched to main library 3D model
    [vitamins_included.kicad_pcb]
2019-07-06 Removed local 3d model
    [UTC016.step]
2019-07-26 Fixed symbols to not rely on rescue
    [left.sch, right.sch, vitamins_included.sch]
2019-10-07 Added footprint for AST1109MLTRQ buzzer
    [left.sch, right.sch, vitamins_included.kicad_pcb]
2019-10-07 Modified reset switch footprint for better manufacturing, and added updated gerbers
    [left.sch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]
2019-10-07 Added ESD protection to connectors
    [left.sch, right.sch, vitamins_included.kicad_pcb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]
2019-10-07 Added series resistors on TRRS
    [left.sch, right.sch, vitamins_included.kicad_pcb]
2020-09-30 Added PE2 pull-down for dfu
    [left.sch, right.sch, vitamins_included.kicad_pcb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]
2020-09-30 saved schematics
    [left.sch, right.sch]
2020-09-30 Updated I2C pull-up values
    Updated the values to ensure the effect of the newly added series resistors don't cause the low level to exceed chip specifications for i2c potentially leading to communication issues if using i2c
    [left.sch, right.sch]
2020-09-30 Removed outdated gerbers and BOM to avoid confusion
    [BOM_vitamins_included.csv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]
2020-09-30 Added updated gerbers, BOM and position files
    [bom.csv, vitamins_included.kicad_pcb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]
2020-10-02 Update values in pcb and ibom
    [vitamins_included.kicad_pcb]
2020-11-16 Added solder pads for SPI
    [vitamins_included.kicad_pcb]
2020-11-16 Exported gerbers
2020-11-16 Added gerbers
    [vitamins_included.kicad_pcb]
2020-12-07 Fixed MISO solder-pad labels
    [vitamins_included.kicad_pcb]
2020-12-07 Fixed sck-gnd short, fixed missing vbus trace
    [vitamins_included.kicad_pcb]
